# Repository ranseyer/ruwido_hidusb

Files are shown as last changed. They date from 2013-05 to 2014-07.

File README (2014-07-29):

************************************************
*                                              *
* RUWIDO V-USB-HID Receiver by Alexander Meyer *
*                                              *
************************************************

This Code is a blend of V-USB and the Ruwido decoder by Guenter Bartsch.
It runs on the ATMega8 as well as the 48-328 family. You also need a
56kHz IR-receiver, e.g. the TSOP1756.

See http://vusb.wikidot.com/hardware for general information on the
USB-interface.

This Package is configured for the USBASP,solder the TSOP output to PIND3 of the controller.

/* ---------------------------- Hardware Config ---------------------------- */

#define USB_CFG_IOPORTNAME      B
/* This is the port where the USB bus is connected. When you configure it to
 * "B", the registers PORTB, PINB and DDRB will be used.
 */
#define USB_CFG_DMINUS_BIT      0
/* This is the bit number in USB_CFG_IOPORT where the USB D- line is connected.
 * This may be any bit in the port.
 */
#define USB_CFG_DPLUS_BIT       1
/* This is the bit number in USB_CFG_IOPORT where the USB D+ line is connected.
 * This may be any bit in the port. Please note that D+ must also be connected
 * to interrupt pin INT0!
 */

This Package is configured for the USBASP,solder the TSOP output to PIND3 of the controller.

TODO:

Aggregation of modifyers does not work correctly yet.
Not all Keycodes are mapped since I didn't find codes for some of the Keys
in the USB-HID spec.

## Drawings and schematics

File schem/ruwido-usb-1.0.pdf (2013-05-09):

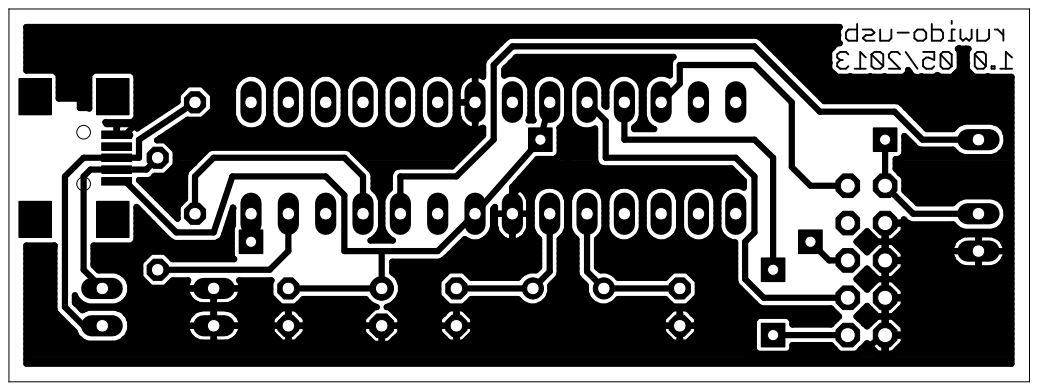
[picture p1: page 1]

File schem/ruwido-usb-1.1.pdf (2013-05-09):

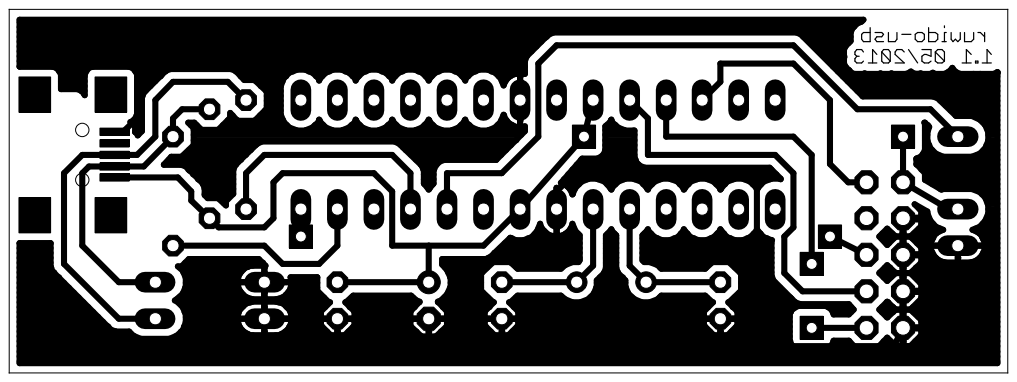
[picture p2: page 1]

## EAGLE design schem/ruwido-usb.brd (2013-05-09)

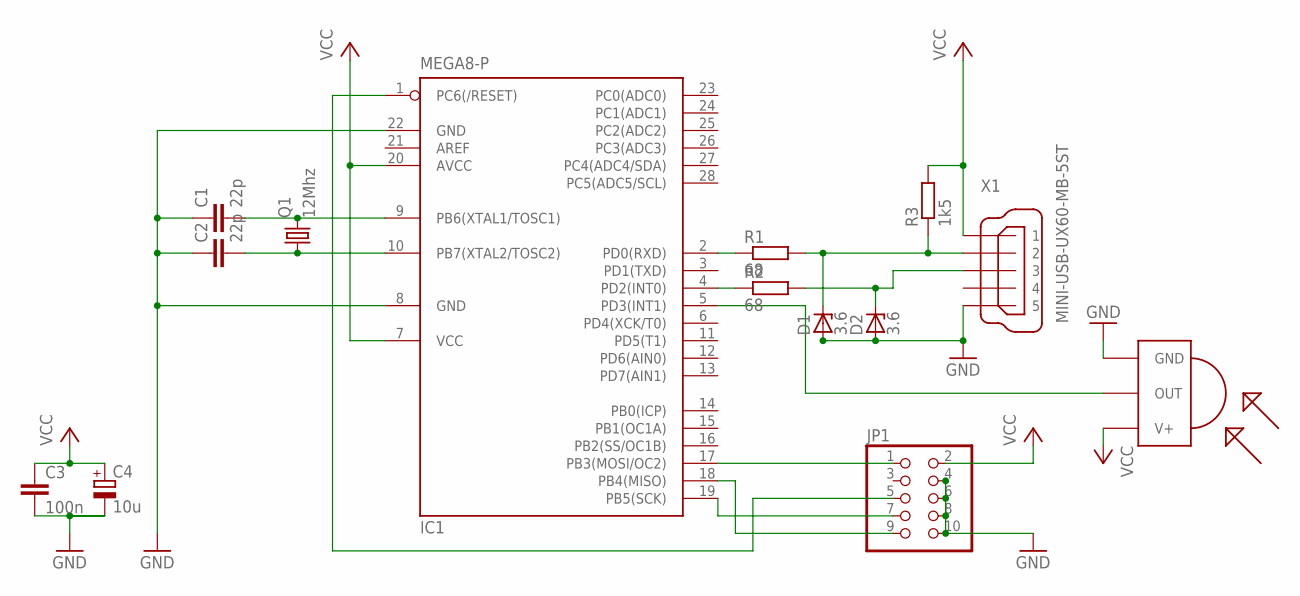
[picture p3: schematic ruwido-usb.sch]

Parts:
C1, C2: 22p; C025-024X044
C3: 100n; C025-024X044
C4: 10u; E2,5-6
D1, D2: 3.6; DO34Z7
IC1: MEGA8-P; DIL28-3
JP1: PINHD-2X5; 2X05
Q1: 12Mhz; HC49U70
R1, R2: 68; 0204/7
R3: 1k5; 0204/7
U$1: TSOP1756; TSOP17XX
X1: MINI-USB-UX60-MB-5ST; UX60-MB-5ST

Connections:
GND: C1.1, C2.1, C3.2, C4.-, D1.A, D2.A, IC1.8 (GND), IC1.22 (GND), JP1.4, JP1.6, JP1.8, JP1.10, U$1.GND, X1.5
unnamed: IC1.2 (PD0(RXD)), R1.1
unnamed: D1.C, R1.2, R3.1, X1.2
unnamed: IC1.4 (PD2(INT0)), R2.1
unnamed: D2.C, R2.2, X1.3
unnamed: C1.2, IC1.9 (PB6(XTAL1/TOSC1)), Q1.2
unnamed: C2.2, IC1.10 (PB7(XTAL2/TOSC2)), Q1.1
unnamed: IC1.5 (PD3(INT1)), U$1.OUT
unnamed: IC1.1 (PC6(/RESET)), JP1.5
unnamed: IC1.17 (PB3(MOSI/OC2)), JP1.1
unnamed: IC1.19 (PB5(SCK)), JP1.7
unnamed: IC1.18 (PB4(MISO)), JP1.9
VCC: C3.1, C4.+, IC1.7 (VCC), IC1.20 (AVCC), JP1.2, R3.2, U$1.V+, X1.1

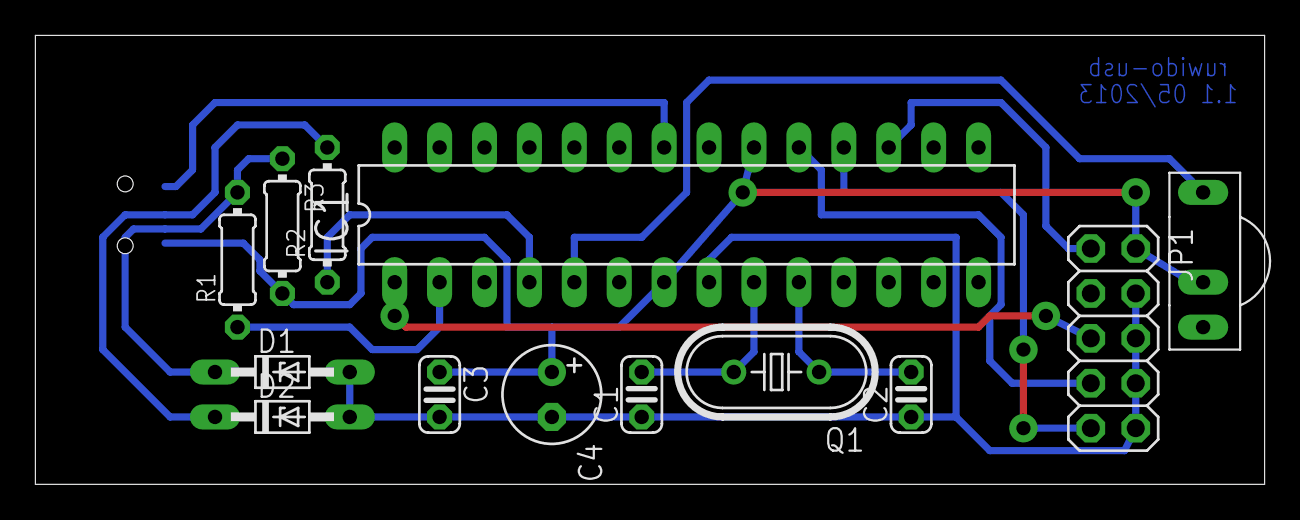
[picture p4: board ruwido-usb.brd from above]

Board: 2 copper layers, 69.5 x 25.4 mm, 14 parts (1 on the bottom side), 13 nets.

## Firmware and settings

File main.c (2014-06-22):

/* Name: main.c
 * Project: RUWIDO Merlin IR-USB-HID-Receiver
 * Author: Alexander Meyer
 * based on HID-Test by Christian Starkjohann, Objective Development
 * and the RUWIDO Merlin IR decoder by Guenter Bartsch
 * Creation Date: 2012-12-13
 * Tabsize: 2
 * Copyright: (c) 2012 Alexander Meyer
 * License: GNU GPL v2 (see License.txt)
 */

#include <avr/io.h>
#include <avr/interrupt.h>
#include <avr/pgmspace.h>
#include <avr/wdt.h>
#include <util/delay.h>
#include <stdlib.h>
#include <inttypes.h>
#include "ir/ir.h"
#include "uart/uart.h"
#include "usbdrv.h"
#include "oddebug.h"
#include "keymap.h"


//#define UART // This breaks USB!!

/* ----------------------- hardware I/O abstraction ------------------------ */

/* pin assignments:
PD0	USB-
PD1	debug tx
PD2	USB+ (int0)
PD3 IR (int1)
*/

static void hardwareInit(void)
{
uchar	i, j;

    PORTB = 0xff;   /* activate all pull-ups */
    DDRB = 0;       /* all pins input */
    PORTC = 0xff;   /* activate all pull-ups */
    DDRC = 0;       /* all pins input */
    PORTD = 0xfa;   /* 1111 1010 bin: activate pull-ups except on USB lines */
    DDRD = 0x07;    /* 0000 0111 bin: all pins input except USB (-> USB reset) */
	j = 0;
	while(--j){     /* USB Reset by device only required on Watchdog Reset */
		i = 0;
		while(--i); /* delay >10ms for USB reset */
	}
    DDRD = 0x02;    /* 0000 0010 bin: remove USB reset condition */
    /* configure timer 0 for a rate of 12M/(1024 * 256) = 45.78 Hz (~22ms) */
    //TCCR0 = 5;      /* timer 0 prescaler: 1024 */
}

static void irInit (void) {

	// port directions

	DDRB = 0 ;
	DDRD = (1<<1) ; // TX


	// IR 


	// timer1 will be used basically as a real time clock
	
	TCCR1A  = 0; // normal mode
        TCCR1B  = (1 << CS12) | (0 << CS11) | (0 << CS10); // prescaler: 256, normal mode

	// IR trigger interrupt

  #if defined (__AVR_ATmega8__) || defined (__AVR_ATmega16__) || defined (__AVR_ATmega32__) || defined (__AVR_ATmega64__) || defined (__AVR_ATmega162__)

 	GIMSK  |= (1<<INT1);     // enable pin change interrupt on PIND3
	MCUCR  |= (1<<ISC10);    // INT1 triggers on any level change

	#else

 	//PCMSK0  = (1<<PCINT1);     // enable pin change interrupt on PINB1
 	//PCICR   = (1<<PCIE0);
 	PCMSK2  = (1<<PCINT19);     // enable pin change interrupt on PIND3
 	PCICR   = (1<<PCIE2);       // enable pcint for int group 2

	#endif

}

#if defined (__AVR_ATmega8__) || defined (__AVR_ATmega16__) || defined (__AVR_ATmega32__) || defined (__AVR_ATmega64__) || defined (__AVR_ATmega162__)
ISR(INT1_vect) { 
	ir_ISR();
} 
#else
//ISR(PCINT0_vect) { 
ISR(PCINT2_vect) { 
	ir_ISR();
} 
#endif

// Lookup Keys from Key Table

uchar mod_key = 0;

static int lookupKey(uint32_t merlinKey) {
	for (int i = 0; i< NUM_MODS; i++) {
		if (modmap[i].merlin == merlinKey) {
// FIX by DD5XL: wrong <= replaced by < in both for loops

			mod_key |= (modmap[i].usb);
			return 0;
		}
	}
	for (int i = 0; i< NUM_KEYS; i++) {
		if (keymap[i].merlin == merlinKey) {
			return keymap[i].usb;
		}
	}
	return 0;
}


// Process key press

volatile uint32_t lastIrCode = 0;

static uchar    keyPressed(void) {

	IR_DATA ird;
	if (ir_get_data(&ird)) {

#if DEBUG_LEVEL > 0
		uart_puts ("IR: ");
		uart_puts (" adr=");
		uart_print16h(ird.address);
		uart_puts (" cmd=");
		uart_print16h(ird.command);
		uart_puts (" flags=");
		uart_print8(ird.flags);
		uart_println ();
#endif

		if (ird.address == 0x2aab) {
			if (ird.command != 0 && ird.flags == 0) {
				lastIrCode = lookupKey(ird.command);
			} else {
				lastIrCode = 0;
			}
		}
	}
	return lastIrCode;
}

/* ------------------------------------------------------------------------- */
/* ----------------------------- USB interface ----------------------------- */
/* ------------------------------------------------------------------------- */

static uchar    reportBuffer[2];    /* buffer for HID reports */
static uchar    idleRate;           /* in 4 ms units */

/* We use a simplifed keyboard report descriptor which does not support the
 * boot protocol. We don't allow setting status LEDs and we only allow one
 * simultaneous key press (except modifiers). We can therefore use short
 * 2 byte input reports.
 * The report descriptor has been created with usb.org's "HID Descriptor Tool"
 * which can be downloaded from http://www.usb.org/developers/hidpage/.
 * Redundant entries (such as LOGICAL_MINIMUM and USAGE_PAGE) have been omitted
 * for the second INPUT item.
 */

const PROGMEM char usbHidReportDescriptor[35] = { /* USB report descriptor */
    0x05, 0x01,                    // USAGE_PAGE (Generic Desktop)
    0x09, 0x06,                    // USAGE (Keyboard)
    0xa1, 0x01,                    // COLLECTION (Application)
    0x05, 0x07,                    //   USAGE_PAGE (Keyboard)
    0x19, 0xe0,                    //   USAGE_MINIMUM (Keyboard LeftControl)
    0x29, 0xe7,                    //   USAGE_MAXIMUM (Keyboard Right GUI)
    0x15, 0x00,                    //   LOGICAL_MINIMUM (0)
    0x25, 0x01,                    //   LOGICAL_MAXIMUM (1)
    0x75, 0x01,                    //   REPORT_SIZE (1)
    0x95, 0x08,                    //   REPORT_COUNT (8)
    0x81, 0x02,                    //   INPUT (Data,Var,Abs)
    0x95, 0x01,                    //   REPORT_COUNT (1)
    0x75, 0x08,                    //   REPORT_SIZE (8)
    0x25, 0x65,                    //   LOGICAL_MAXIMUM (101)
    0x19, 0x00,                    //   USAGE_MINIMUM (Reserved (no event indicated))
    0x29, 0x65,                    //   USAGE_MAXIMUM (Keyboard Application)
    0x81, 0x00,                    //   INPUT (Data,Ary,Abs)
    0xc0                           // END_COLLECTION
};


// Build USB Report

static void buildReport(uchar key) {
	reportBuffer[0] = mod_key;
	reportBuffer[1] = key;
	mod_key = 0;
}

uchar	usbFunctionSetup(uchar data[8]) {
	
		usbRequest_t    *rq = (void *)data;

    usbMsgPtr = reportBuffer;
    if((rq->bmRequestType & USBRQ_TYPE_MASK) == USBRQ_TYPE_CLASS){    // class request type
        if(rq->bRequest == USBRQ_HID_GET_REPORT){  // wValue: ReportType (highbyte), ReportID (lowbyte)
            // we only have one report type, so don't look at wValue
            buildReport(keyPressed());
            return sizeof(reportBuffer);
        }else if(rq->bRequest == USBRQ_HID_GET_IDLE){
            usbMsgPtr = &idleRate;
            return 1;
        }else if(rq->bRequest == USBRQ_HID_SET_IDLE){
            idleRate = rq->wValue.bytes[1];
        }
    }else{
        // no vendor specific requests implemented
    }
	return 0;
}


/* ------------------------------------------------------------------------- */


int	main(void)
{
uchar   key, lastKey = 0, keyDidChange = 0;
uchar   idleCounter = 0;

	wdt_enable(WDTO_2S);
	hardwareInit();
	odDebugInit();
	usbInit();
	irInit();

#if DEBUG_LEVEL > 0
	uart_println();
	uart_println();
	uart_println();
	uart_puts ("IR test\r\n");
	uart_println();
#endif

	sei();
    DBG1(0x00, 0, 0);
	for(;;){	/* main event loop */
		wdt_reset();
		usbPoll();
					key = keyPressed();
					if(lastKey != key){
							lastKey = key;
							keyDidChange = 1;
					}
					#if defined (__AVR_ATmega8__) || defined (__AVR_ATmega16__) || defined (__AVR_ATmega32__) || defined (__AVR_ATmega64__) || defined (__AVR_ATmega162__)
					if(TIFR & (1<<TOV0)){   // 22 ms timer 
							TIFR = 1<<TOV0;
					#else
					if(TIFR0 & (1<<TOV0)){   // 22 ms timer 
							TIFR0 = 1<<TOV0;
					#endif
							if(idleRate != 0){
									if(idleCounter > 4){
											idleCounter -= 5;   // 22 ms in units of 4 ms
									}else{
											idleCounter = idleRate;
											keyDidChange = 1;
									}
							}
					}
					if(keyDidChange && usbInterruptIsReady()){
							keyDidChange = 0;
							// use last key and not current key status in order to avoid lost changes in key status.
							buildReport(lastKey);
							usbSetInterrupt(reportBuffer, sizeof(reportBuffer));
					}
	}
	return 0;
}

/* ------------------------------------------------------------------------- */

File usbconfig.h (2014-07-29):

/* Name: usbconfig.h
 * Project: AVR USB driver
 * Author: Christian Starkjohann
 * Creation Date: 2005-04-01
 * Tabsize: 4
 * Copyright: (c) 2005 by OBJECTIVE DEVELOPMENT Software GmbH
 * License: GNU GPL v2 (see License.txt) or proprietary (CommercialLicense.txt)
 * This Revision: $Id: usbconfig.h 300 2007-03-29 17:07:35Z cs $
 */

#ifndef __usbconfig_h_included__
#define __usbconfig_h_included__

/*
General Description:
This file contains parts of the USB driver which can be configured and can or
must be adapted to your hardware.

Please note that the usbdrv contains a usbconfig-prototype.h file now. We
recommend that you use that file as a template because it will always list
the newest features and options.
*/

/* ---------------------------- Hardware Config ---------------------------- */

#define USB_CFG_IOPORTNAME      B
/* This is the port where the USB bus is connected. When you configure it to
 * "B", the registers PORTB, PINB and DDRB will be used.
 */
#define USB_CFG_DMINUS_BIT      0
/* This is the bit number in USB_CFG_IOPORT where the USB D- line is connected.
 * This may be any bit in the port.
 */
#define USB_CFG_DPLUS_BIT       1 
/* This is the bit number in USB_CFG_IOPORT where the USB D+ line is connected.
 * This may be any bit in the port. Please note that D+ must also be connected
 * to interrupt pin INT0!
 */
#define USB_CFG_CLOCK_KHZ       (F_CPU/1000)
/* Clock rate of the AVR in kHz. Legal values are 12000, 12800, 15000, 16000,
 * 16500, 18000 and 20000. The 12.8 MHz and 16.5 MHz versions of the code
 * require no crystal, they tolerate +/- 1% deviation from the nominal
 * frequency. All other rates require a precision of 2000 ppm and thus a
 * crystal!
 * Since F_CPU should be defined to your actual clock rate anyway, you should
 * not need to modify this setting.
 */
#define USB_CFG_CHECK_CRC       0
/* Define this to 1 if you want that the driver checks integrity of incoming
 * data packets (CRC checks). CRC checks cost quite a bit of code size and are
 * currently only available for 18 MHz crystal clock. You must choose
 * USB_CFG_CLOCK_KHZ = 18000 if you enable this option.
 */

/* ----------------------- Optional Hardware Config ------------------------ */

/* #define USB_CFG_PULLUP_IOPORTNAME   D */
/* If you connect the 1.5k pullup resistor from D- to a port pin instead of
 * V+, you can connect and disconnect the device from firmware by calling
 * the macros usbDeviceConnect() and usbDeviceDisconnect() (see usbdrv.h).
 * This constant defines the port on which the pullup resistor is connected.
 */
/* #define USB_CFG_PULLUP_BIT          4 */
/* This constant defines the bit number in USB_CFG_PULLUP_IOPORT (defined
 * above) where the 1.5k pullup resistor is connected. See description
 * above for details.
 */

/* --------------------------- Functional Range ---------------------------- */
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

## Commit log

2013-05-01 Use Arduino to program.
2013-05-09 Added EAGLE files.
    [ruwido-usb.brd, ruwido-usb.sch]
2014-06-22 Some minor bugs fixed
    [ir.c, main.c]

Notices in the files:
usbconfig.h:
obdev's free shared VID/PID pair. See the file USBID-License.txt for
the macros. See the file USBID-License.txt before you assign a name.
